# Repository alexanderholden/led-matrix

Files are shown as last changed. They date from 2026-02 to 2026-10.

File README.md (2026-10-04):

# LED matrix sign

## Key features
  - Multiplexed LED matrix
  - Adjustable brightness
  - Custom PCB and hardware design
  - WiFi enabled to allow for on-demand display changes
## System architecture
1. LED Matrix
   - LEDs arranged as an NxM grid
   - Rows and columns multiplexed reducing pin usage
  
2. Driver
   - 74HC595 attached to columns handle low side switching
   - CD4017 decade counters with transistors attached to rows handling scanning
  
3. Microcontroller
   - Generates clock signal
   - Updates frame buffer
   - Wi-Fi server

## Renders

- LED board


- Driver board


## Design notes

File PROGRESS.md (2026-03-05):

# Prototype 1:

- Making the LED matrix itself so I can test on a breadboard
- It is 16x8 and the end product will be probably around 320x160 or similar size
- I have sent the PCB off to manufacturing and will probably get it back in 2-3 days
- Next stage is to get LED driver ICs/shift registers/decade counters
led-matrix-transparent

-26/02/26 - PCB has been fabricated and will solder LEDs in a couple days

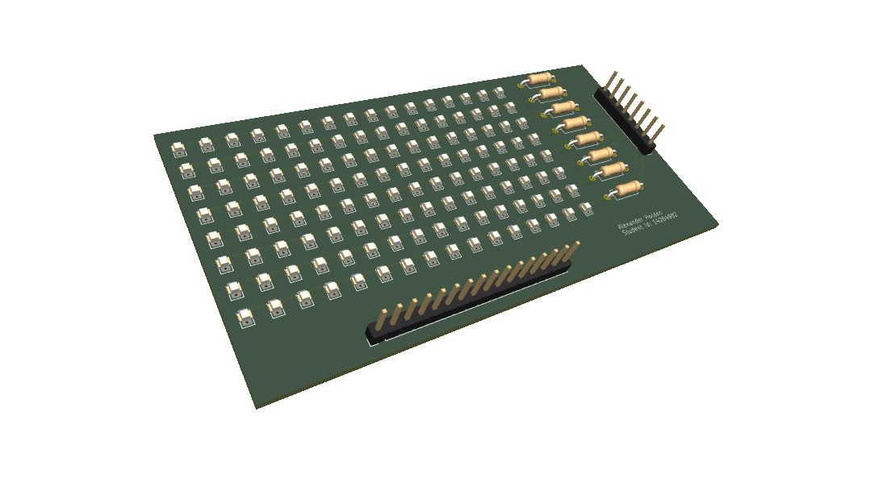
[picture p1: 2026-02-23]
Images/led-matrix-transparent.png

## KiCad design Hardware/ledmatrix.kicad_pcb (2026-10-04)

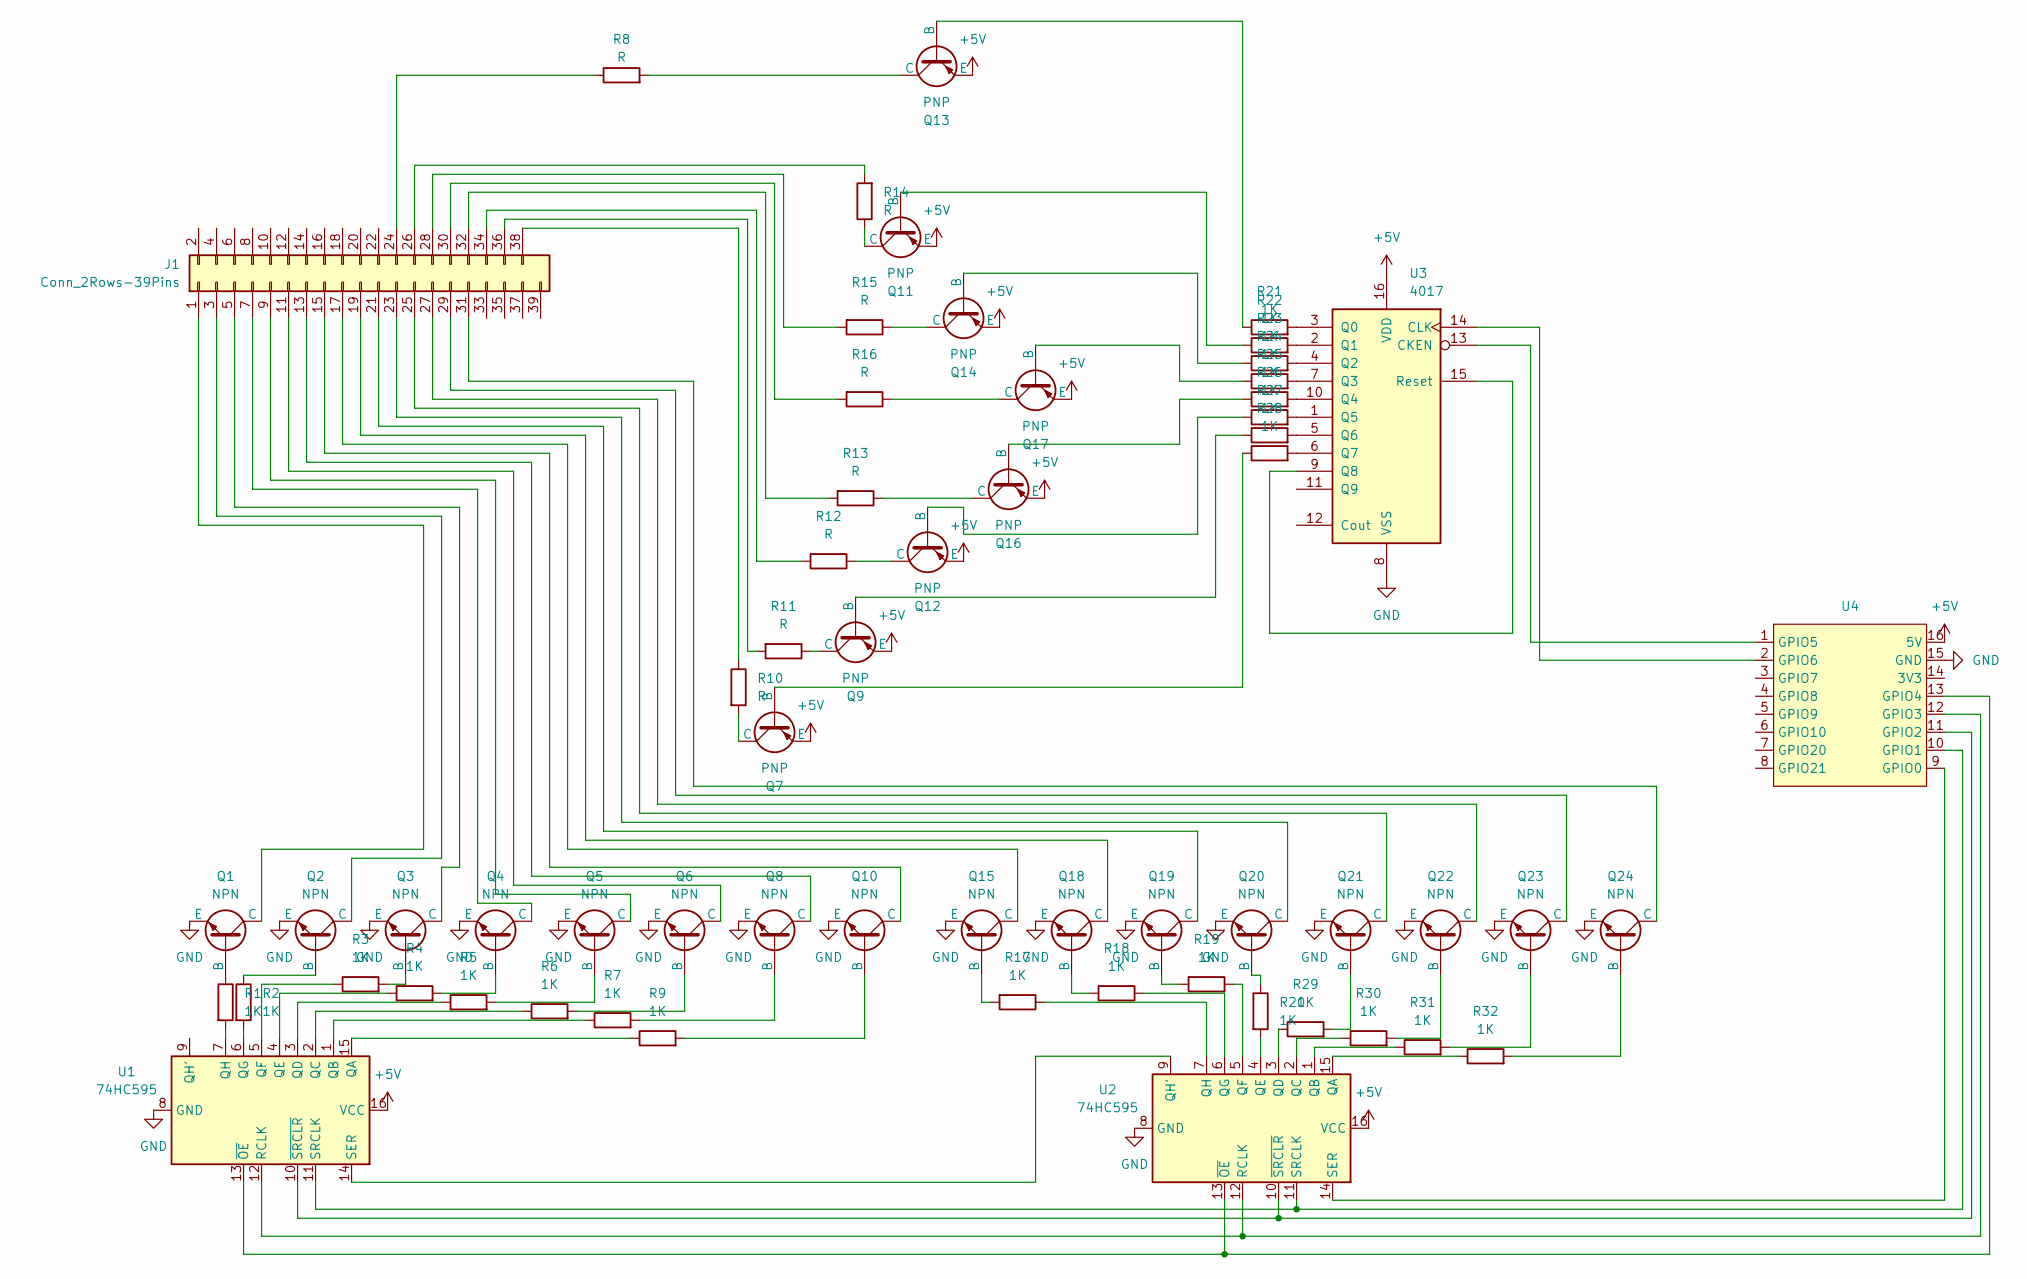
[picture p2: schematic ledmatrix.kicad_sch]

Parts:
J1: Conn_2Rows-39Pins; PinHeader_2x20_P2.54mm_Vertical
Q1, Q2, Q3, Q4, Q5, Q6, Q8, Q10, Q15, Q18, Q19, Q20, Q21, Q22, Q23, Q24: NPN; TO-92
Q7, Q9, Q11, Q12, Q13, Q14, Q16, Q17: PNP; TO-92
R1, R2, R3, R4, R5, R6, R7, R9, R17, R18, R19, R20, R21, R22, R23, R24, R25, R26, R27, R28, R29, R30, R31, R32: 1K; R_Axial_DIN0207_L6.3mm_D2.5mm_P10.16mm_Horizontal
R8, R10, R11, R12, R13, R14, R15, R16: R; R_Axial_DIN0207_L6.3mm_D2.5mm_P10.16mm_Horizontal
U1, U2: 74HC595; DIP-16_W7.62mm
U3: 4017; DIP-16_W7.62mm
U4: ESP32-C3-SuperMini

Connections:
+5V: Q7.3 (E), Q9.3 (E), Q11.3 (E), Q12.3 (E), Q13.3 (E), Q14.3 (E), Q16.3 (E), Q17.3 (E), U1.16 (VCC), U2.16 (VCC), U3.16 (VDD), U4.16 (5V)
GND: Q1.3 (E), Q2.3 (E), Q3.3 (E), Q4.3 (E), Q5.3 (E), Q6.3 (E), Q8.3 (E), Q10.3 (E), Q15.3 (E), Q18.3 (E), Q19.3 (E), Q20.3 (E), Q21.3 (E), Q22.3 (E), Q23.3 (E), Q24.3 (E), U1.8 (GND), U2.8 (GND), U3.8 (VSS), U4.15 (GND)
unnamed: J1.1, Q1.1 (C)
unnamed: J1.3, Q2.1 (C)
unnamed: J1.5, Q3.1 (C)
unnamed: J1.7, Q4.1 (C)
unnamed: J1.9, Q5.1 (C)
unnamed: J1.11, Q6.1 (C)
unnamed: J1.13, Q8.1 (C)
unnamed: J1.15, Q10.1 (C)
unnamed: J1.17, Q15.1 (C)
unnamed: J1.19, Q18.1 (C)
unnamed: J1.21, Q19.1 (C)
unnamed: J1.23, Q20.1 (C)
unnamed: J1.24, R8.1
unnamed: J1.25, Q21.1 (C)
unnamed: J1.26, R14.2
unnamed: J1.27, Q22.1 (C)
unnamed: J1.28, R15.2
unnamed: J1.29, Q23.1 (C)
unnamed: J1.30, R16.2
unnamed: J1.31, Q24.1 (C)
unnamed: J1.32, R13.2
unnamed: J1.34, R12.2
unnamed: J1.36, R11.2
unnamed: J1.38, R10.1
unnamed: Q1.2 (B), R1.1
unnamed: Q2.2 (B), R2.1
unnamed: Q3.2 (B), R3.2
unnamed: Q4.2 (B), R4.2
unnamed: Q5.2 (B), R5.2
unnamed: Q6.2 (B), R6.2
unnamed: Q7.2 (B), R28.1
unnamed: Q7.1 (C), R10.2
unnamed: Q8.2 (B), R7.2
unnamed: Q9.2 (B), R27.1
unnamed: Q9.1 (C), R11.1
unnamed: Q10.2 (B), R9.2
unnamed: Q11.2 (B), R22.1
unnamed: Q11.1 (C), R14.1
unnamed: Q12.2 (B), R26.1
unnamed: Q12.1 (C), R12.1
unnamed: Q13.2 (B), R21.1
unnamed: Q13.1 (C), R8.2
unnamed: Q14.2 (B), R23.1
unnamed: Q14.1 (C), R15.1
unnamed: Q15.2 (B), R17.2
unnamed: Q16.2 (B), R25.1
unnamed: Q16.1 (C), R13.1
unnamed: Q17.2 (B), R24.1
unnamed: Q17.1 (C), R16.1
unnamed: Q18.2 (B), R18.2
unnamed: Q19.2 (B), R19.2
unnamed: Q20.2 (B), R20.1
unnamed: Q21.2 (B), R29.2
unnamed: Q22.2 (B), R30.2
unnamed: Q23.2 (B), R31.2
unnamed: Q24.2 (B), R32.2
unnamed: R9.1, U1.15 (QA)
unnamed: R7.1, U1.1 (QB)
unnamed: R6.1, U1.2 (QC)
unnamed: R5.1, U1.3 (QD)
unnamed: R4.1, U1.4 (QE)
unnamed: R3.1, U1.5 (QF)
unnamed: R2.2, U1.6 (QG)
unnamed: R1.2, U1.7 (QH)
unnamed: U1.12 (RCLK), U2.12 (RCLK), U4.12 (GPIO3)
unnamed: U1.14 (SER), U2.9 (QH')
unnamed: U1.11 (SRCLK), U2.11 (SRCLK), U4.10 (GPIO1)
unnamed: U1.13 (~OE), U2.13 (~OE), U4.13 (GPIO4)
unnamed: U1.10 (~SRCLR), U2.10 (~SRCLR), U4.11 (GPIO2)
unnamed: R32.1, U2.15 (QA)
unnamed: R31.1, U2.1 (QB)
unnamed: R30.1, U2.2 (QC)
unnamed: R29.1, U2.3 (QD)
unnamed: R20.2, U2.4 (QE)
unnamed: R19.1, U2.5 (QF)
unnamed: R18.1, U2.6 (QG)
unnamed: R17.1, U2.7 (QH)
unnamed: U2.14 (SER), U4.9 (GPIO0)
unnamed: U3.13 (CKEN), U4.1 (GPIO5)
unnamed: U3.14 (CLK), U4.2 (GPIO6)
unnamed: R21.2, U3.3 (Q0)
unnamed: R22.2, U3.2 (Q1)
unnamed: R23.2, U3.4 (Q2)
unnamed: R24.2, U3.7 (Q3)
unnamed: R25.2, U3.10 (Q4)
unnamed: R26.2, U3.1 (Q5)
unnamed: R27.2, U3.5 (Q6)
unnamed: R28.2, U3.6 (Q7)
unnamed: U3.9 (Q8), U3.15 (Reset)

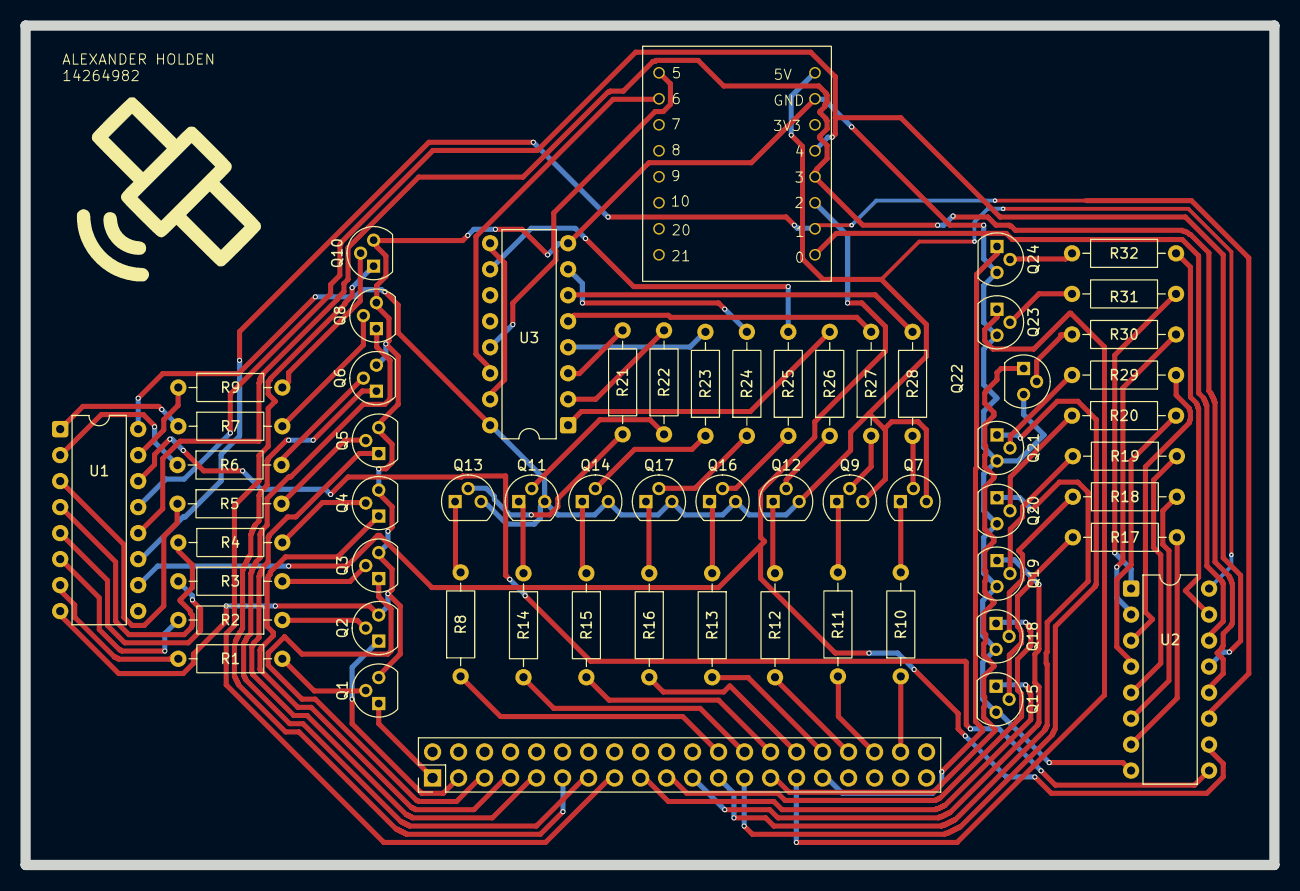
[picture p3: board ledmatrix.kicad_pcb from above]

Board: 2 copper layers, 122.0 x 82.0 mm, 61 parts (0 on the bottom side), 91 nets.

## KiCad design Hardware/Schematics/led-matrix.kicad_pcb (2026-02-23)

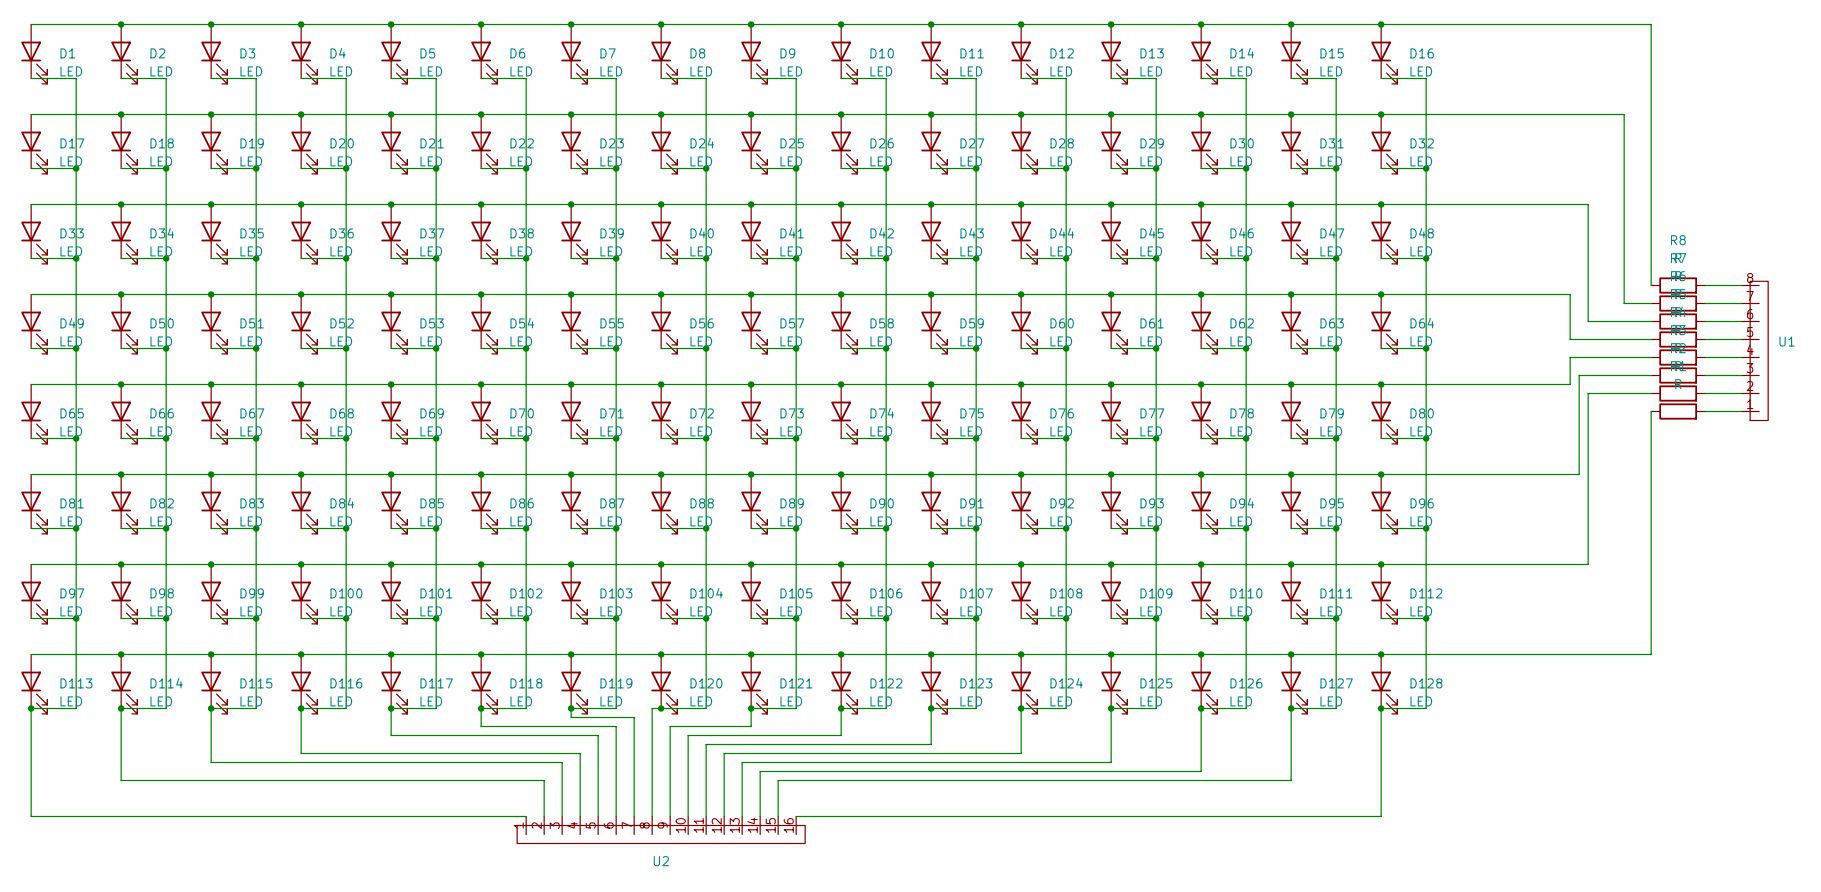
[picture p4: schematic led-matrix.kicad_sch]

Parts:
D1, D2, D3, D4, D5, D6, D7, D8, D9, D10, D11, D12, D13, D14, D15, D16, D17, D18, D19, D20, D21, D22, D23, D24, D25, D26, D27, D28, D29, D30, D31, D32, D33, D34, D35, D36, D37, D38, D39, D40, D41, D42, D43, D44, D45, D46, D47, D48, D49, D50, D51, D52, D53, D54, D55, D56, D57, D58, D59, D60, D61, D62, D63, D64, D65, D66, D67, D68, D69, D70, D71, D72, D73, D74, D75, D76, D77, D78, D79, D80, D81, D82, D83, D84, D85, D86, D87, D88, D89, D90, D91, D92, D93, D94, D95, D96, D97, D98, D99, D100, D101, D102, D103, D104, D105, D106, D107, D108, D109, D110, D111, D112, D113, D114, D115, D116, D117, D118, D119, D120, D121, D122, D123, D124, D125, D126, D127, D128: LED; LED_0805_2012Metric_45
R1, R2, R3, R4, R5, R6, R7, R8: R; R_Axial_DIN0207_L6.3mm_D2.5mm_P10.16mm_Horizontal
U1: PinHeader_1x08_P2.54mm_Vertical
U2: PinHeader_1x16_P2.54mm_Vertical

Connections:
unnamed: D1.2 (A), D2.2 (A), D3.2 (A), D4.2 (A), D5.2 (A), D6.2 (A), D7.2 (A), D8.2 (A), D9.2 (A), D10.2 (A), D11.2 (A), D12.2 (A), D13.2 (A), D14.2 (A), D15.2 (A), D16.2 (A), R8.1
unnamed: D1.1 (K), D17.1 (K), D33.1 (K), D49.1 (K), D65.1 (K), D81.1 (K), D97.1 (K), D113.1 (K), U2.1
unnamed: D10.1 (K), D26.1 (K), D42.1 (K), D58.1 (K), D74.1 (K), D90.1 (K), D106.1 (K), D122.1 (K), U2.10
unnamed: D17.2 (A), D18.2 (A), D19.2 (A), D20.2 (A), D21.2 (A), D22.2 (A), D23.2 (A), D24.2 (A), D25.2 (A), D26.2 (A), D27.2 (A), D28.2 (A), D29.2 (A), D30.2 (A), D31.2 (A), D32.2 (A), R7.1
unnamed: D33.2 (A), D34.2 (A), D35.2 (A), D36.2 (A), D37.2 (A), D38.2 (A), D39.2 (A), D40.2 (A), D41.2 (A), D42.2 (A), D43.2 (A), D44.2 (A), D45.2 (A), D46.2 (A), D47.2 (A), D48.2 (A), R6.1
unnamed: D49.2 (A), D50.2 (A), D51.2 (A), D52.2 (A), D53.2 (A), D54.2 (A), D55.2 (A), D56.2 (A), D57.2 (A), D58.2 (A), D59.2 (A), D60.2 (A), D61.2 (A), D62.2 (A), D63.2 (A), D64.2 (A), R5.1
unnamed: D65.2 (A), D66.2 (A), D67.2 (A), D68.2 (A), D69.2 (A), D70.2 (A), D71.2 (A), D72.2 (A), D73.2 (A), D74.2 (A), D75.2 (A), D76.2 (A), D77.2 (A), D78.2 (A), D79.2 (A), D80.2 (A), R4.1
unnamed: D81.2 (A), D82.2 (A), D83.2 (A), D84.2 (A), D85.2 (A), D86.2 (A), D87.2 (A), D88.2 (A), D89.2 (A), D90.2 (A), D91.2 (A), D92.2 (A), D93.2 (A), D94.2 (A), D95.2 (A), D96.2 (A), R3.1
unnamed: D97.2 (A), D98.2 (A), D99.2 (A), D100.2 (A), D101.2 (A), D102.2 (A), D103.2 (A), D104.2 (A), D105.2 (A), D106.2 (A), D107.2 (A), D108.2 (A), D109.2 (A), D110.2 (A), D111.2 (A), D112.2 (A), R2.1
unnamed: D4.1 (K), D20.1 (K), D36.1 (K), D52.1 (K), D68.1 (K), D84.1 (K), D100.1 (K), D116.1 (K), U2.4
unnamed: D5.1 (K), D21.1 (K), D37.1 (K), D53.1 (K), D69.1 (K), D85.1 (K), D101.1 (K), D117.1 (K), U2.5
unnamed: D6.1 (K), D22.1 (K), D38.1 (K), D54.1 (K), D70.1 (K), D86.1 (K), D102.1 (K), D118.1 (K), U2.6
unnamed: D7.1 (K), D23.1 (K), D39.1 (K), D55.1 (K), D71.1 (K), D87.1 (K), D103.1 (K), D119.1 (K), U2.7
unnamed: D8.1 (K), D24.1 (K), D40.1 (K), D56.1 (K), D72.1 (K), D88.1 (K), D104.1 (K), D120.1 (K), U2.8
unnamed: D9.1 (K), D25.1 (K), D41.1 (K), D57.1 (K), D73.1 (K), D89.1 (K), D105.1 (K), D121.1 (K), U2.9
unnamed: D11.1 (K), D27.1 (K), D43.1 (K), D59.1 (K), D75.1 (K), D91.1 (K), D107.1 (K), D123.1 (K), U2.11
unnamed: D12.1 (K), D28.1 (K), D44.1 (K), D60.1 (K), D76.1 (K), D92.1 (K), D108.1 (K), D124.1 (K), U2.12
unnamed: D13.1 (K), D29.1 (K), D45.1 (K), D61.1 (K), D77.1 (K), D93.1 (K), D109.1 (K), D125.1 (K), U2.13
unnamed: D14.1 (K), D30.1 (K), D46.1 (K), D62.1 (K), D78.1 (K), D94.1 (K), D110.1 (K), D126.1 (K), U2.14
unnamed: D15.1 (K), D31.1 (K), D47.1 (K), D63.1 (K), D79.1 (K), D95.1 (K), D111.1 (K), D127.1 (K), U2.15
unnamed: D16.1 (K), D32.1 (K), D48.1 (K), D64.1 (K), D80.1 (K), D96.1 (K), D112.1 (K), D128.1 (K), U2.16
unnamed: D113.2 (A), D114.2 (A), D115.2 (A), D116.2 (A), D117.2 (A), D118.2 (A), D119.2 (A), D120.2 (A), D121.2 (A), D122.2 (A), D123.2 (A), D124.2 (A), D125.2 (A), D126.2 (A), D127.2 (A), D128.2 (A), R1.1
unnamed: D2.1 (K), D18.1 (K), D34.1 (K), D50.1 (K), D66.1 (K), D82.1 (K), D98.1 (K), D114.1 (K), U2.2
unnamed: D3.1 (K), D19.1 (K), D35.1 (K), D51.1 (K), D67.1 (K), D83.1 (K), D99.1 (K), D115.1 (K), U2.3
unnamed: R1.2, U1.1
unnamed: R2.2, U1.2
unnamed: R3.2, U1.3
unnamed: R4.2, U1.4
unnamed: R5.2, U1.5
unnamed: R6.2, U1.6
unnamed: R7.2, U1.7
unnamed: R8.2, U1.8

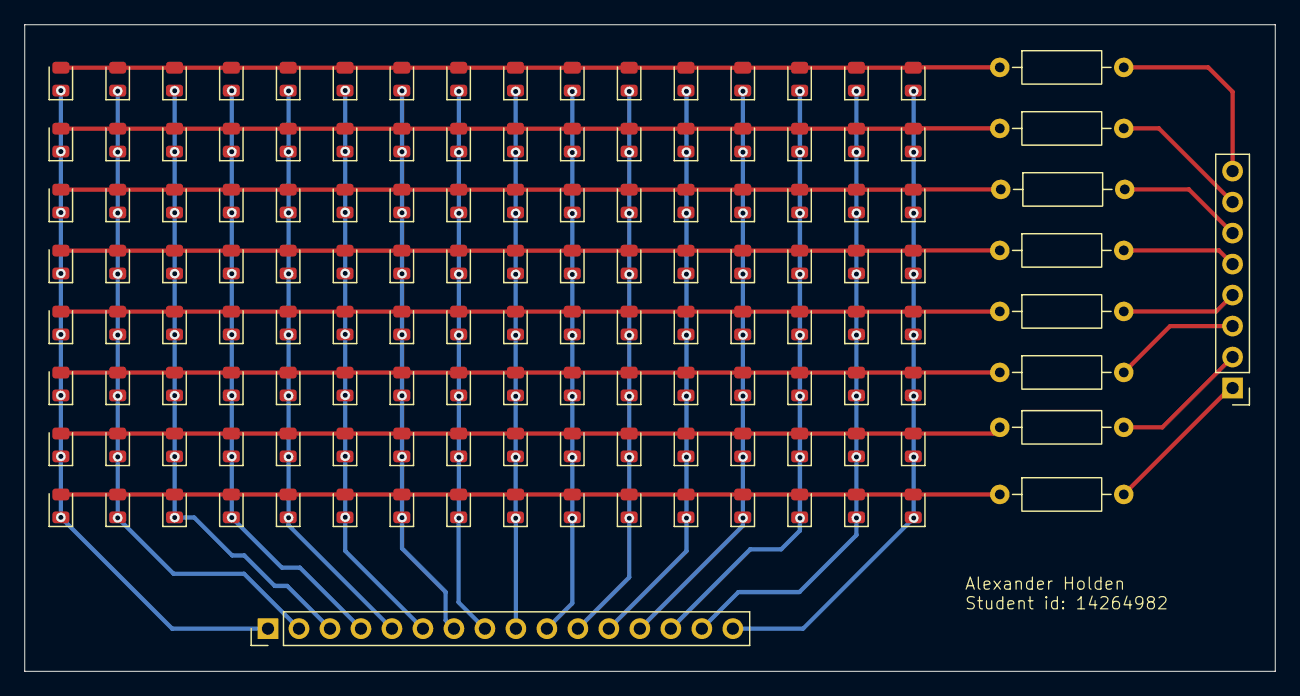
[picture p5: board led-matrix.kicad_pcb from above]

Board: 2 copper layers, 102.5 x 53.0 mm, 138 parts (0 on the bottom side), 32 nets.

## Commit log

2026-02-21 schematic updated
    [led-matrix.kicad_pcb, led-matrix.kicad_sch]
2026-02-22 finished small design for testing, now sending to university pcb for fabrication
    [led-matrix.kicad_pcb, led-matrix.kicad_sch]
2026-02-22 added resistors to rows
    [led-matrix-B_Cu.gbr, led-matrix-B_Mask.gbr, led-matrix-B_Paste.gbr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]
2026-02-22 made slight adjustments
    [led-matrix-B_Cu.gbr, led-matrix-B_Mask.gbr, led-matrix-B_Paste.gbr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]
2026-02-23 pcb pics
2026-03-05 clean up
    [led-matrix-B_Cu.gbr, led-matrix-B_Mask.gbr, led-matrix-B_Paste.gbr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]
2026-10-04 Add files via upload
    LED matrix backend
    [ledmatrix.kicad_pcb, ledmatrix.kicad_sch]
